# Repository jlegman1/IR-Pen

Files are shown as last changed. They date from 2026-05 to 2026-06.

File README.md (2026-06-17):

## Disclaimer
This project is intended for educational and research purposes only. It should be used responsibly and only in environments where you have permission to transmit infrared signals.
##
I created a PCB created that sends IR signals to TVs. You click a button and it uses TV-B-Gone firmware to cycle through all IR signals until a TV turns off. A custom 3d printed shell goes around it hiding the pcb. All kicad files and 3d print files linked. I had created this project because I was playing around with my flipper zero and thought how funny it was to when I turned the tv off when my dad was watching. It gave me motiavtion to create something of my own, so which i did. Overall I hope you enjoy playing around with my desgin!
PCB fits through my 3d printed shell and should fit there tightly but shouldn't fall out. Its diamater is 13mm and its 133mm in height. The PCB is 11mm x 65mm.
##
Firmware created by Mitch Altman and adafruit [TV-B-Gone](https://github.com/adafruit/TV-B-Gone-kit)
## Parts List

- **10440 Lithium Battery 3.7V** — power source that slides into pen body — [Amazon](https://www.amazon.com/dp/B0H1LNY5LW)
- **USBasp Programmer** — for flashing firmware via ISP pads — [Amazon](https://rb.gy/d68i6x)
- **Tactile Button** — trigger to fire IR codes — [DigiKey](https://www.digikey.com/en/products/detail/c-k/PTS526SM15SMTR2-LFS/10056625)
- **10µF Capacitor** — handles big voltage dips — [DigiKey](https://www.digikey.com/en/products/detail/murata-electronics/GRM155R60J106ME05D/11500166)
- **100nF Capacitor** — smooths out voltage spikes — [DigiKey](https://www.digikey.com/en/products/detail/murata-electronics/GRM155R61A104KA01D/587212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)
- **33Ω Resistor** — limits current to IR LED — [DigiKey](https://www.digikey.com/en/products/detail/yageo/RC0402JR-0733RL/726467)
- **3.3kΩ Resistor** — keeps charging at 300mA — [DigiKey](https://www.digikey.com/en/products/detail/panasonic-industry/ERA-2AEB332X/1706017)
- **10kΩ Resistors x2** — keeps ATtiny RESET and button pin stable — [DigiKey](https://www.digikey.com/en/products/detail/stackpole-electronics-inc/RMCF0402FT10K0/1761433)
- **USB-C Connector** — charges the battery — [DigiKey](https://www.digikey.com/en/products/detail/gct/USB4085-GF-A/9859662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)
- **2N7002 MOSFET** — switch that drives the IR LED — [DigiKey](https://www.digikey.com/en/products/detail/onsemi/2N7002ET1G/1792136)
- **Keystone 5223** — battery spring contact — [DigiKey](https://www.digikey.com/en/products/detail/keystone-electronics/5223/316374)
- **TSAL6400** — IR LED — [DigiKey](https://www.digikey.com/en/products/detail/vishay-semiconductor-opto-division/TSAL6400/1681340)
- **MCP73831T** — battery charger IC — [DigiKey](https://www.digikey.com/en/products/detail/microchip-technology/MCP73831T-2ATI-OT/964303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)
- **ATtiny85-20SU** — main microcontroller — [DigiKey](https://www.digikey.com/en/products/detail/microchip-technology/ATTINY85-20SU/735470)
- Downloadable CSV up top
##

Screenshot 2026-05-26 at 2 52 33 PM

Screenshot 2026-05-26 at 11 50 53 AM
Screenshot 2026-05-27 at 10 30 16 PM

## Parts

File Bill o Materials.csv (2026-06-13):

Bill of Materials
 | Part | Qty | Purpose | Link
 | 10440 Lithium Battery 3.7V | 1 | Power source that slides into pen body | https://www.amazon.com/dp/B0H1LNY5LW
 | USBasp Programmer | 1 | For flashing firmware via ISP pads | https://rb.gy/d68i6x
 | Tactile Button | 1 | Trigger to fire IR codes | https://www.digikey.com/en/products/detail/c-k/PTS526SM15SMTR2-LFS/10056625
 | 10uF Capacitor | 1 | Handles big voltage dips | https://www.digikey.com/en/products/detail/murata-electronics/GRM155R60J106ME05D/11500166
 | 100nF Capacitor | 1 | Smooths out voltage spikes | https://www.digikey.com/en/products/detail/murata-electronics/GRM155R61A104KA01D/587212
 | 33 Ohm Resistor | 1 | Limits current to IR LED | https://www.digikey.com/en/products/detail/yageo/RC0402JR-0733RL/726467
 | 3.3k Ohm Resistor | 1 | Sets charging current behavior | https://www.digikey.com/en/products/detail/panasonic-industry/ERA-2AEB332X/1706017
 | 10k Ohm Resistor | 2 | Pull-ups for RESET and button stability | https://www.digikey.com/en/products/detail/stackpole-electronics-inc/RMCF0402FT10K0/1761433
 | USB-C Connector | 1 | Charging port | https://www.digikey.com/en/products/detail/gct/USB4085-GF-A/9859662
 | 2N7002 MOSFET | 1 | Switch for driving IR LED | https://www.digikey.com/en/products/detail/onsemi/2N7002ET1G/1792136
 | Keystone 5223 | 1 | Battery spring contact | https://www.digikey.com/en/products/detail/keystone-electronics/5223/316374
 | TSAL6400 IR LED | 1 | Infrared emitter LED | https://www.digikey.com/en/products/detail/vishay-semiconductor-opto-division/TSAL6400/1681340
 | MCP73831T | 1 | Battery charger IC | https://www.digikey.com/en/products/detail/microchip-technology/MCP73831T-2ATI-OT/964303
 | ATtiny85-20SU | 1 | Main microcontroller | https://www.digikey.com/en/products/detail/microchip-technology/ATTINY85-20SU/735470

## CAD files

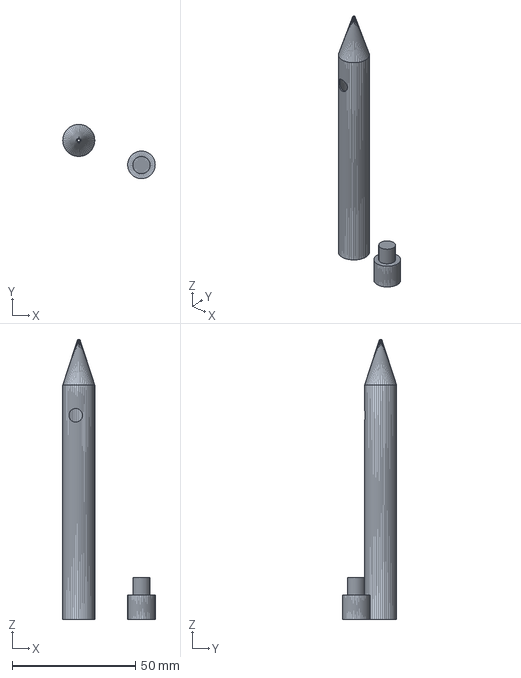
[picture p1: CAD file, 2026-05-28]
3d print models/IR pen body.step
37.5 x 22.0 x 113.5 mm
STEP translator 7.5 1.1
STEP translator 7.5 1.2

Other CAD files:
3d print models/IR pen body.stl

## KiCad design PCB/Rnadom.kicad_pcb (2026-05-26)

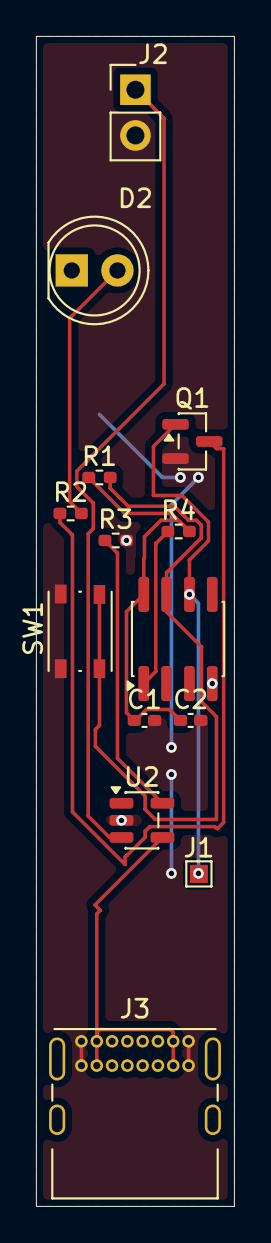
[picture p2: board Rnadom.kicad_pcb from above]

Board: 2 copper layers, 11.0 x 65.0 mm, 14 parts (0 on the bottom side), 10 nets.

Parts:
C1: 100n; C_0402_1005Metric_Pad0.74x0.62mm_HandSolder
C2: 10u; C_0402_1005Metric_Pad0.74x0.62mm_HandSolder
D2: LED; LED_D5.0mm
J1: Conn_01x06; TestPoint_Pad_1.0x1.0mm
J2: Conn_01x02; PinHeader_1x02_P2.54mm_Vertical
J3: USB_C_Receptacle_USB2.0_14P; USB_C_Receptacle_GCT_USB4085
Q1: 2N7002; SOT-23
R1, R4: 10k; R_0402_1005Metric_Pad0.72x0.64mm_HandSolder
R2: 33; R_0402_1005Metric_Pad0.72x0.64mm_HandSolder
R3: 3.3k; R_0402_1005Metric_Pad0.72x0.64mm_HandSolder
SW1: SW_Push; SW_Push_1P1T_NO_Vertical_Wuerth_434133025816
U1: ATtiny85-20S; SOIC-8_3.9x4.9mm_P1.27mm
U2: MCP73831-2-OT; SOT-23-5

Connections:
/PB1: J1.1 (Pin_1_1), Q1.1 (G), U1.6 (PB1)
/PB2: R1.2, SW1.2, U1.7 (PB2)
/PB5: R4.1, U1.1 (~RESET/PB5)
/PROG: R3.1, U2.5 (PROG)
/VBAT: J2.1, U2.3 (V_{BAT})
/VBUS: J3.A4 (VBUS), J3.A9 (VBUS), J3.B4 (VBUS), J3.B9 (VBUS), U2.4 (V_{DD})
GND: C1.2, C2.2, J2.2, J3.A1 (GND), J3.A12 (GND), J3.B1 (GND), J3.B12 (GND), Q1.2 (S), R3.2, SW1.1, U1.4 (GND), U2.2 (V_{SS})
unnamed: D2.2 (A), R2.2
unnamed: Q1.3 (D), R2.1
VCC: C1.1, C2.1, R1.1, R4.2, U1.8 (VCC)

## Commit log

2026-06-12 Create PCB files
2026-06-12 Create Kicad files
